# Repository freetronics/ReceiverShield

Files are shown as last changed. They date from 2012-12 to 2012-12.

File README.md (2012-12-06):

Freetronics 315MHz / 433MHz Receiver Shield
===========================================
Copyright 2011 Freetronics Pty Ltd  
Freetronics site:  <www.freetronics.com>  
Freetronics email: <info@freetronics.com>  

A general-purpose 315MHz / 433MHz receiver shield for the Arduino
and other microcontroller boards based on the same header format, such
as the Freetronics Eleven.

Includes significant prototyping area using the spare shield area.

Note that this design uses 0603 surface-mount parts and is intended for
machine assembly, but could still be assembled by hand with a fine-tip
soldering iron, a steady hand, and some magnification.

Features:

 * Reset button wired through to Arduino reset pin.
 * Two general-purpose surface-mount LEDs wired to GND via current-
   limiting resistors (drive HIGH to illuminate).
 * Pads for 2 surface-mount 100nF smoothing capacitors.
 * Parts overlay on both the top and the bottom so you can see what you
   are connecting without turning the board over.

More information is available on our product page at:

  http://www.freetronics.com/receiver

The "docs" folder within this repository includes a handy copy of the
schematic in PDF format and the Getting Started guide.

INSTALLATION
------------
The design is saved as an EAGLE project. EAGLE PCB design software is
available from www.cadsoftusa.com free for non-commercial use. To use
this project download it and place the directory containing these files
into the "eagle" directory on your computer. Then open EAGLE and
navigate to Projects -> eagle -> ReceiverShield.

DISTRIBUTION
------------
The specific terms of distribution of this project are governed by the
license referenced below.

LICENSE
-------
Licensed under the TAPR Open Hardware License (www.tapr.org/OHL).
The "license" folder within this repository also contains a copy of
this license in plain text format.

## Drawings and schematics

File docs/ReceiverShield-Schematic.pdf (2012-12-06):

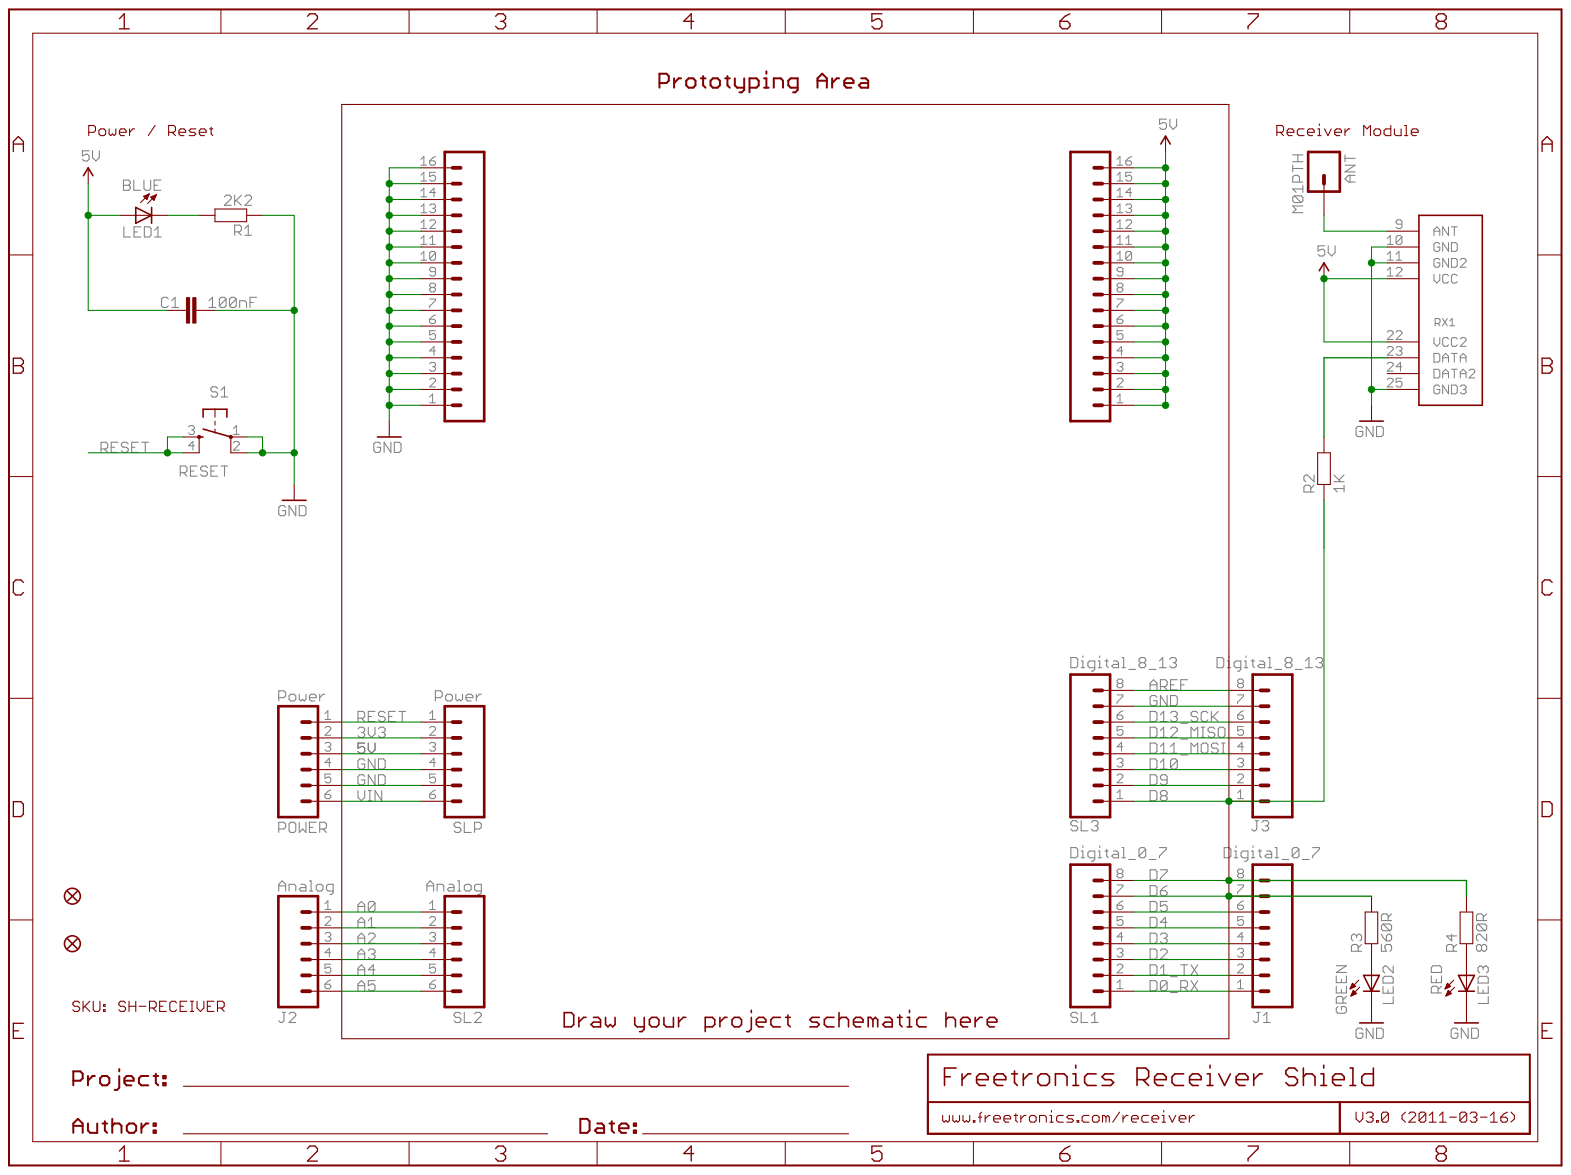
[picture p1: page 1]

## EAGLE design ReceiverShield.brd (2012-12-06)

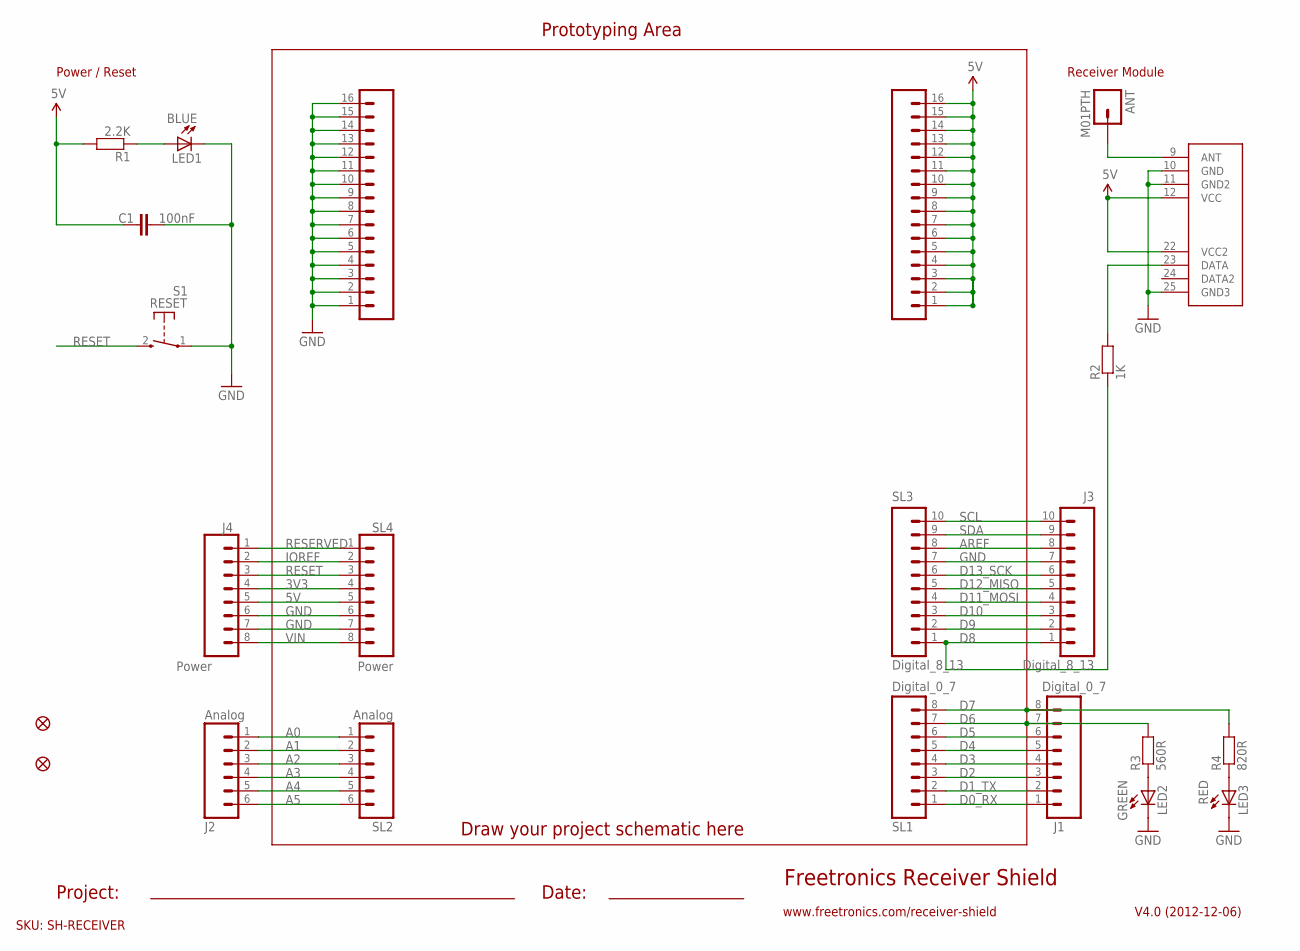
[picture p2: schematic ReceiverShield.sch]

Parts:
ANT: M01PTH; 1X01
C1: 100nF; 0603
J1: Digital_0_7; 1X08
J2: Analog; 1X06
J3: Digital_8_13; 1X10
J4: Power; 1X08
LED1: BLUE; LED-0603
LED2: GREEN; LED-0603
LED3: RED; LED-0603
PADS_5V: M16PTH; 1X16
PADS_GND: M16PTH; 1X16
R1: 2.2K; 0603
R2: 1K; 0603
R3: 560R; 0603
R4: 820R; 0603
RX1: RXB1SIL; RX-B1
S1: RESET; TACTILE_SWITCH_SMD_2PIN_TINY
SL1: Digital_0_7; 1X08
SL2: Analog; 1X06
SL3: Digital_8_13; 1X10
SL4: Power; 1X08
U$4, U$5: FIDUCIAL1X2.5; FIDUCIAL-1X2.5

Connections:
3V3: J4.4, SL4.4
5V: C1.1, J4.5, PADS_5V.1, PADS_5V.2, PADS_5V.3, PADS_5V.4, PADS_5V.5, PADS_5V.6, PADS_5V.7, PADS_5V.8, PADS_5V.9, PADS_5V.10, PADS_5V.11, PADS_5V.12, PADS_5V.13, PADS_5V.14, PADS_5V.15, PADS_5V.16, R1.2, RX1.12 (VCC), RX1.22 (VCC2), SL4.5
A0: J2.1, SL2.1
A1: J2.2, SL2.2
A2: J2.3, SL2.3
A3: J2.4, SL2.4
A4: J2.5, SL2.5
A5: J2.6, SL2.6
AREF: J3.8, SL3.8
D0_RX: J1.1, SL1.1
D1_TX: J1.2, SL1.2
D2: J1.3, SL1.3
D3: J1.4, SL1.4
D4: J1.5, SL1.5
D5: J1.6, SL1.6
D6: J1.7, R3.2, SL1.7
D7: J1.8, R4.2, SL1.8
D8: J3.1, R2.1, SL3.1
D9: J3.2, SL3.2
D10: J3.3, SL3.3
D11_MOSI: J3.4, SL3.4
D12_MISO: J3.5, SL3.5
D13_SCK: J3.6, SL3.6
GND: C1.2, J3.7, J4.6, J4.7, LED1.C, LED2.C, LED3.C, PADS_GND.1, PADS_GND.2, PADS_GND.3, PADS_GND.4, PADS_GND.5, PADS_GND.6, PADS_GND.7, PADS_GND.8, PADS_GND.9, PADS_GND.10, PADS_GND.11, PADS_GND.12, PADS_GND.13, PADS_GND.14, PADS_GND.15, PADS_GND.16, RX1.10 (GND), RX1.11 (GND2), RX1.25 (GND3), S1.1, SL3.7, SL4.6, SL4.7
IOREF: J4.2, SL4.2
unnamed: LED1.A, R1.1
unnamed: LED2.A, R3.1
unnamed: LED3.A, R4.1
unnamed: ANT.1, RX1.9 (ANT)
unnamed: R2.2, RX1.23 (DATA)
RESERVED: J4.1, SL4.1
RESET: J4.3, S1.2 (S), SL4.3
SCL: J3.10, SL3.10
SDA: J3.9, SL3.9
VIN: J4.8, SL4.8

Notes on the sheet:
Prototyping Area
Freetronics Receiver Shield
SKU: SH-RECEIVER
V4.0 (2012-12-06)
Power / Reset
Draw your project schematic here
Project:
Date:
Receiver Module
www.freetronics.com/receiver-shield

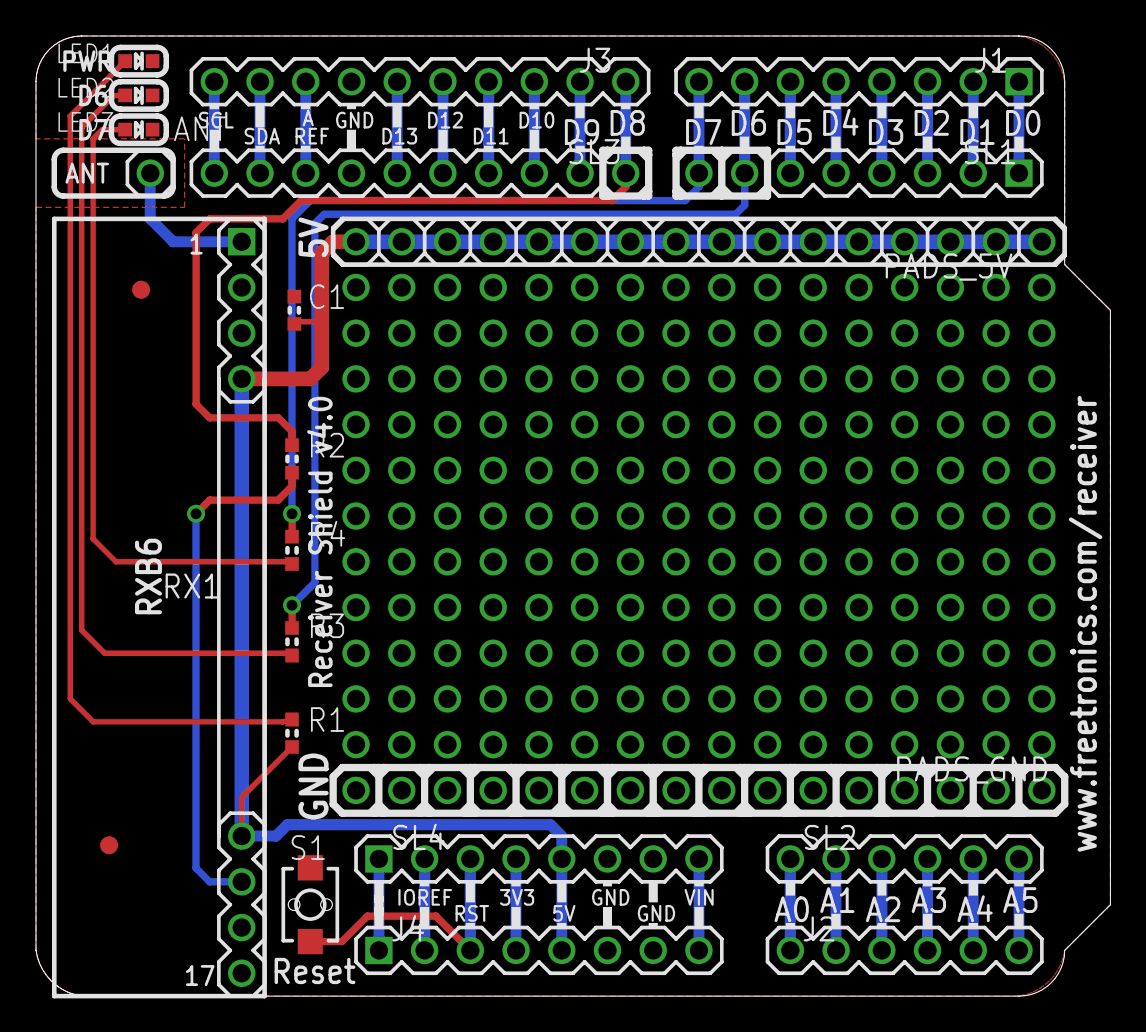
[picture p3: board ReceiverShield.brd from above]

Board: 2 copper layers, 59.7 x 53.3 mm, 23 parts (0 on the bottom side), 35 nets.

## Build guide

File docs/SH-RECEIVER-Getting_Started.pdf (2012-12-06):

## ASK Receiver Shield (315MHz or 433MHz)

www.freetronics.com/receiver

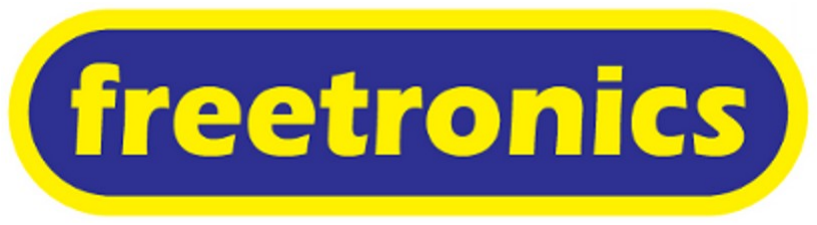
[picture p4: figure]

The ASK Receiver Shield gives your Arduino the ability to receive and decode radio signals transmitted on the unlicensed 315MHz or 433MHz band (depending on model) using ASK (Amplitude Shift Keying) or OOK (On-Off Keying) modulation. ASK signals at these frequencies are very commonly used by consumer electronics devices including weather stations, power consumption meters, security systems, and home automation controllers.

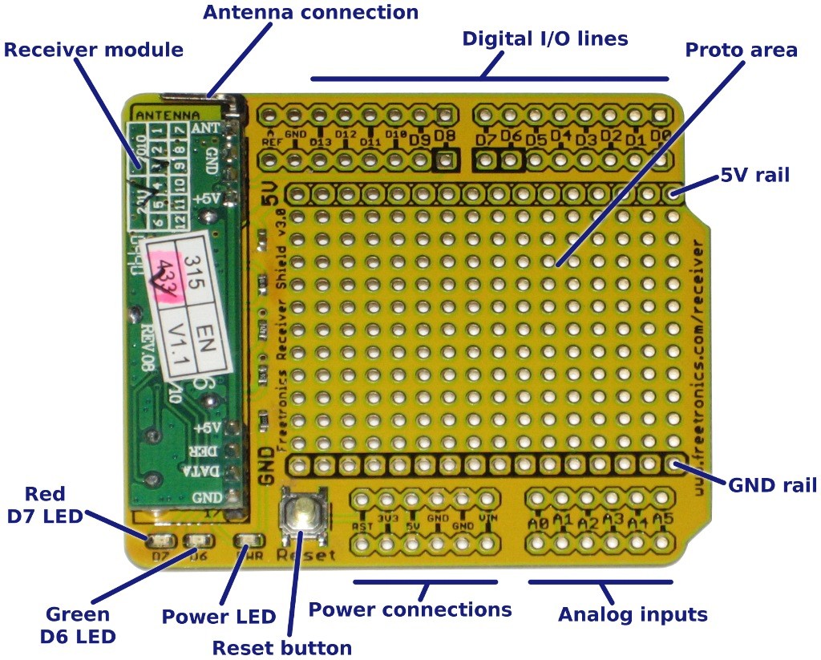
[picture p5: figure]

This shield implements the same circuit as the “Weather Station Receiver” project documented in the book Practical Arduino, so it will work perfectly with the example software in that project. You can learn more about it at: www.practicalarduino.com/projects/weather-station-receiver

## Specifications

Tuned frequency: | 315MHz or 433.92MHz, depending on model
Sensitivity: | -110dBm
Data connection: | D8
Red status LED: | D7 (active high)
Green status LED: | D6 (active high)
| 1

## Hardware Setup

### 1. The shield is provided without any headers installed so that you can decide

whether you want to use regular headers or stackable headers. Follow the instructions on our website to install whichever type you prefer: www.freetronics.com/soldering-shield-headers.
2. Fit the ASK Receiver Shield to your Arduino.
3. Connect the antenna.

## Software Setup

There are a variety of projects available to suit this shield. You can find details referenced at:
www.freetronics.com/receiver.

## Support

For assistance see www.freetronics.com/support or email support@freetronics.com. For general Arduino support please see www.arduino.cc/forum.

## Arduino Books

Getting Started With Arduino by Massimo Banzi

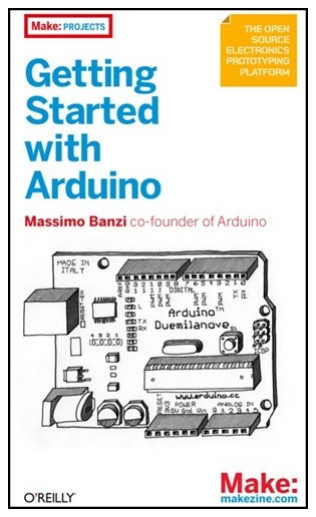
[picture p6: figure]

A gently introduction to using your Arduino for the first time: how to connect it up, load programs onto it, and do some basic experiments to give you a feel for how it works. Great introduction for the first-time Arduino user. 128 pages. www.oreilly.com/pub/pr/2115

Practical Arduino by Jonathan Oxer and Hugh Blemings

Taking you far beyond the basics, this book blends theory and practice by using example projects to illustrate some of the more advanced things you can do with Arduino and how to apply those concepts to your own designs. After working through this book you'll be very confident designing and building your own Arduino creations. 445 pages. www.practicalarduino.com

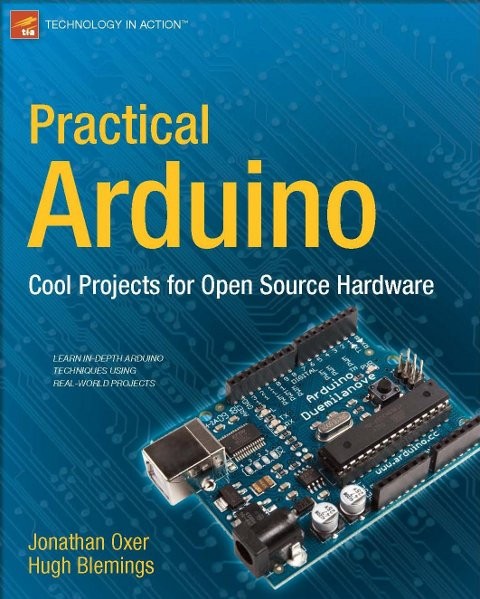
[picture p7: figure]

## About Freetronics

Freetronics is an Australian company created by Jonathan Oxer and Marc Alexander to provide easy access to hardware, parts, and products related to Arduino projects and the book Practical Arduino. Learn more at www.freetronics.com. Follow us on Twitter at twitter.com/freetronics.

2

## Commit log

2010-11-01 Initial import of v3 files
    [ReceiverShield.brd, ReceiverShield.sch]
2011-04-20 Updated docs and project for release version
    [ReceiverShield.brd, ReceiverShield.sch]
2012-12-06 Version 4.0 release with R3 headers
    [ReceiverShield.brd, ReceiverShield.sch]

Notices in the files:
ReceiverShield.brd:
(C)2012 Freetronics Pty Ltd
